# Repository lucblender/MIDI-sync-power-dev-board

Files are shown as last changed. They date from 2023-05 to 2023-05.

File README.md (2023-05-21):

# MIDI-sync-power-dev-board

The MIDI-sync-power-dev-board is a 4hp eurorack module created to be used either as an expander for other board or as a standalone module helping you developping electronic.
The module provides :
- an isolated 5V 400mA
- a 3.3V 200mA from LDO
- a Sync in from 3.5mm jack (use as sync, gate, trigger, ...)
	- 0-xV signal input transformed to TTL level (signal is inverted)
- a MIDI input or MIDI output configurable through soldering jumper
	- Can only use one configuration at a time!

The module has a 2x a 10 pins header on top and bottom that gives you access to eurorack +12V and -12V, the board 5V and 3.3V, the Sync signal, the MIDI in or MIDI out signal. 

| Signal names| |
|---|---|
| +5V | +3.3V |
| +12V | -12V |
| GND | GND |
| MIDI OUT | GND |
| Sync IN  | MIDI IN |

The idea behind this module came while developping my own synth that needed MIDI input. I had to make my own little MIDI In through optocoupler on breadboard or veroboard each time. 

Additonally, I created the [Canvas](https://github.com/lucblender/simple_canvas) synthesizer in collaboration with [Synthux Academy](https://www.synthux.academy). And the board did not have MIDI input or sync in making it hard to sync with any synthesizer setup. To not add complexity to the design, I prefered to create this little expander that I now use to power the Canvas and use Sync in and MIDI input.

## Schematic

Schematic

## PCB

|Top|Bottom|
|----|----|
|top|bottom|

### MIDI configuration

|MIDI in|MIDI out|
|----|----|
|On the bottom, you need to solder JP1 and JP2|On the top, you need to solder JP3, JP4 and JP5|

*Reminder*: You can only use one MIDI configuration at a time!

## Front panel

The MIDI-sync-power-dev-board has mutliple front panel since it can be use for various reason.
- midi-sync-module-front-panel-**a**: Dedicated to the Canvas
- midi-sync-module-front-panel-**b**: Generic Sync In, MIDI OUT
- midi-sync-module-front-panel-**c**: Generic Sync In, MIDI IN

All the front panel are double sided. On the Top you will find a the debug front panel with 10 pins header description. And on the Bottom you will find the custom design.

### Front Panel Example

| front-panel-**a**-top|front-panel-**a**-bottom|front-panel-**b**-top|front-panel-**b**-bottom|front-panel-**c**-top|front-panel-**c**-bottom|
|----|----|----|----|----|----|
|a-top|TODO|b-top|b-bottom|c-top|c-bottom||

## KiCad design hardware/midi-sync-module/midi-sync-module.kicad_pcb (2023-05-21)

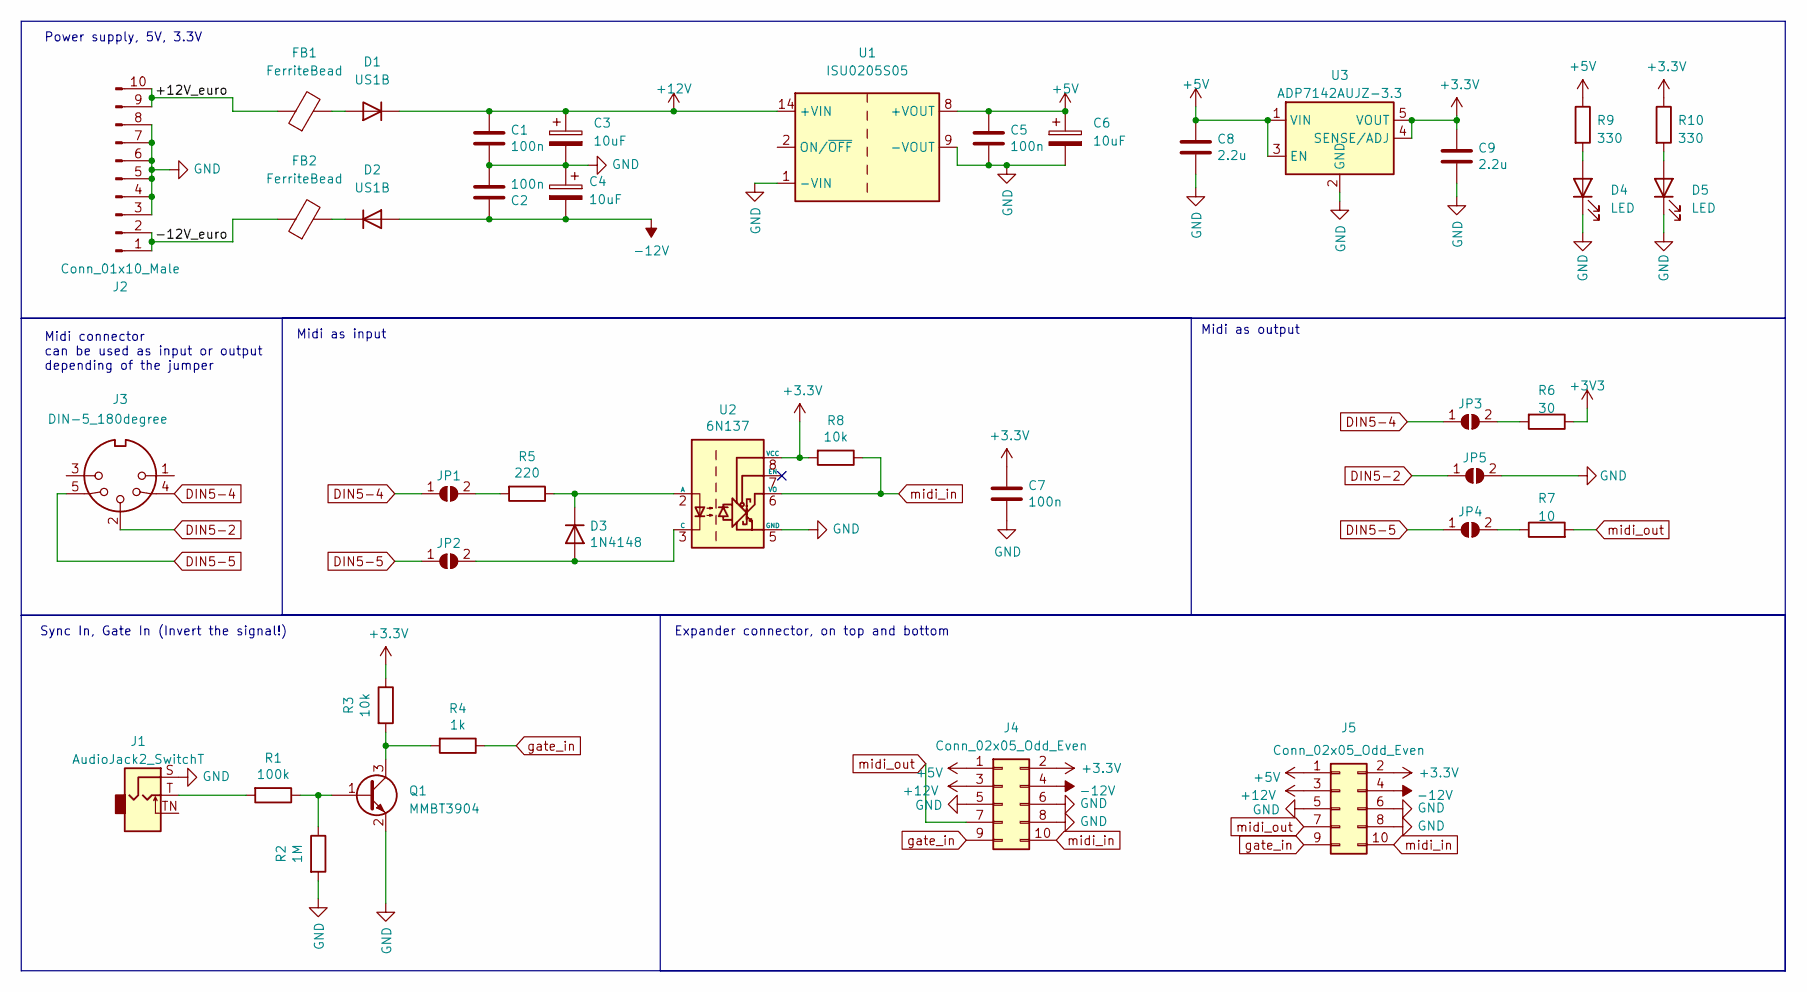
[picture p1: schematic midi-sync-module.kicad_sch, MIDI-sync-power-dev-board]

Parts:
C1, C2, C5, C7: 100n; C_0603_1608Metric; LCSC C14663
C3, C4, C6: 10uF; CP_Elec_6.3x5.9
C8, C9: 2.2u; C_0805_2012Metric; LCSC C14663
D1, D2: US1B; D_SMA
D3: 1N4148; D_SOD-123; LCSC C81598
D4, D5: LED; LED_D3.0mm
FB1, FB2: FerriteBead; L_0805_2012Metric
J1: AudioJack2_SwitchT; Jack_3.5mm_QingPu_WQP-PJ301BM_Vertical
J2: Conn_01x10_Male; PinHeader_2x05_P2.54mm_Vertical
J3: DIN-5_180degree; CUI_SD-50BV
J4: Conn_02x05_Odd_Even; PinHeader_2x05_P2.54mm_Vertical_SMD
J5: Conn_02x05_Odd_Even; PinHeader_2x05_P2.54mm_Horizontal
JP1, JP2, JP3, JP4, JP5: SolderJumper_2_Open; SolderJumper-2_P1.3mm_Open_Pad1.0x1.5mm
Q1: MMBT3904; SOT-23
R1: 100k; R_0603_1608Metric; LCSC C22962
R2: 1M; R_0603_1608Metric; LCSC C22962
R3: 10k; R_0603_1608Metric; LCSC C22962
R4: 1k; R_0603_1608Metric; LCSC C22962
R5: 220; R_0603_1608Metric; LCSC C22962
R6: 30; R_0805_2012Metric
R7: 10; R_0805_2012Metric
R8: 10k; R_0603_1608Metric; LCSC C25804
R9, R10: 330; R_0805_2012Metric
U1: ISU0205S05; Converter_DCDC_XP_POWER-ISU02_SMD
U2: 6N137; SMDIP-8_W9.53mm; LCSC C110020
U3: ADP7142AUJZ-3.3; TSOT-23-5

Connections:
+5V: C5.1, C6.1, C8.1, J4.1, J5.1, R9.1, U1.8 (+VOUT), U3.1 (VIN), U3.3 (EN)
+12V: C1.1, C3.1, D1.1 (K), J4.3, J5.3, U1.14 (+VIN)
-12V: C2.1, C4.2, D2.2 (A), J4.4, J5.4
/+12V_euro: FB1.1, J2.9, J2.10
/-12V_euro: FB2.1, J2.1, J2.2
DIN5-2: J3.2, JP5.1 (A)
DIN5-4: J3.4, JP1.1 (A), JP3.1 (A)
DIN5-5: J3.5, JP2.1 (A), JP4.1 (A)
GND: C1.2, C2.2, C3.2, C4.1, C5.2, C6.2, C7.2, C8.2, C9.2, D4.1 (K), D5.1 (K), J1.S, J2.3, J2.4, J2.5, J2.6, J2.7, J2.8, J4.5, J4.6, J4.8, J5.5, J5.6, J5.8, JP5.2 (B), Q1.2 (E), R2.2, U1.1 (-VIN), U1.9 (-VOUT), U2.5 (GND), U3.2 (GND)
unnamed: D1.2 (A), FB1.2
unnamed: D2.1 (K), FB2.2
unnamed: D3.2 (A), JP2.2 (B), U2.3 (C)
unnamed: D3.1 (K), R5.1, U2.2 (A)
unnamed: D4.2 (A), R9.2
unnamed: D5.2 (A), R10.2
unnamed: J1.T, R1.2
unnamed: JP1.2 (B), R5.2
unnamed: JP3.2 (B), R6.2
unnamed: JP4.2 (B), R7.1
unnamed: Q1.1 (B), R1.1, R2.1
unnamed: Q1.3 (C), R3.2, R4.2
gate_in: J4.9, J5.9, R4.1
midi_in: J4.10, J5.10, R8.1, U2.6 (VO)
midi_out: J4.7, J5.7, R7.2

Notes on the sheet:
Midi connector can be used as input or output depending of the jumper
Midi as output
Expander connector, on top and bottom
Midi as input
Power supply, 5V, 3.3V
Sync In, Gate In (Invert the signal!)

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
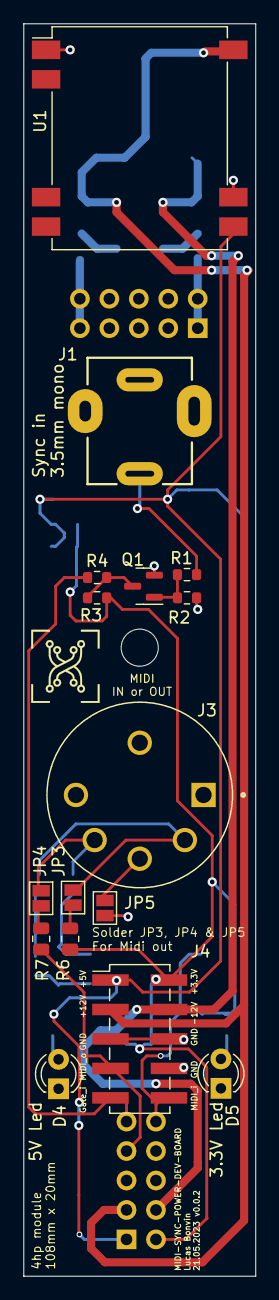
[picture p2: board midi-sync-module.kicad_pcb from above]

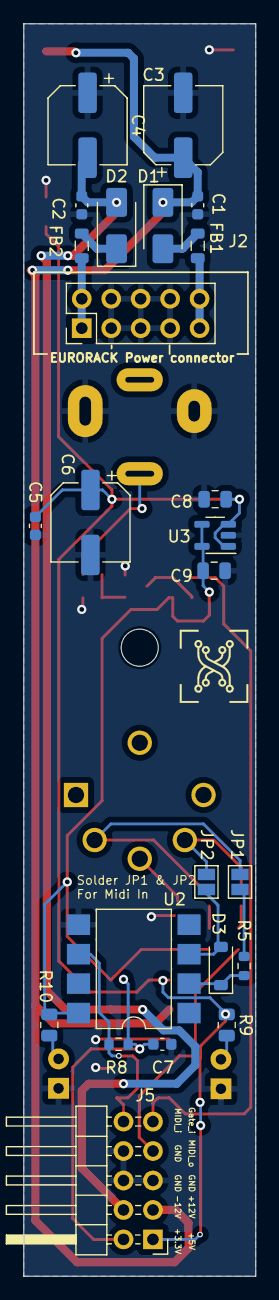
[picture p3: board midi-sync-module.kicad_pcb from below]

Board: 2 copper layers, 20.0 x 108.0 mm, 40 parts (24 on the bottom side), 25 nets.

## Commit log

2023-05-21 add main pcb
    [midi-sync-module-B_Cu.gbr, midi-sync-module-B_Mask.gbr, midi-sync-module-B_Paste.gbr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]
2023-05-21 add front panel a
    [midi-sync-module-front-pannel-a.kicad_pcb, midi-sync-module-front-pannel-a.kicad_sch]
2023-05-21 add front panel b
    [midi-sync-module-front-pannel-b.kicad_pcb, midi-sync-module-front-pannel-b.kicad_sch]
2023-05-21 add front panel c
    [midi-sync-module-front-pannel-c.kicad_pcb, midi-sync-module-front-pannel-c.kicad_sch]
2023-05-21 update pbc to v0.0.2 (fix polarized cap C3 and some texts) and panel c
    [midi-sync-module-B_Cu.gbr, midi-sync-module-B_Mask.gbr, midi-sync-module-B_Paste.gbr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]
2023-05-21 why do I keep putting to n to panel
    [midi-sync-module-front-panel-a.kicad_pcb, midi-sync-module-front-panel-a.kicad_sch, midi-sync-module-front-panel-b.kicad_pcb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]
